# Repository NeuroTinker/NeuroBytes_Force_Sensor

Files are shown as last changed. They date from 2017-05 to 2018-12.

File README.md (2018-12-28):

# NeuroBytes Pressure Sensory Neuron
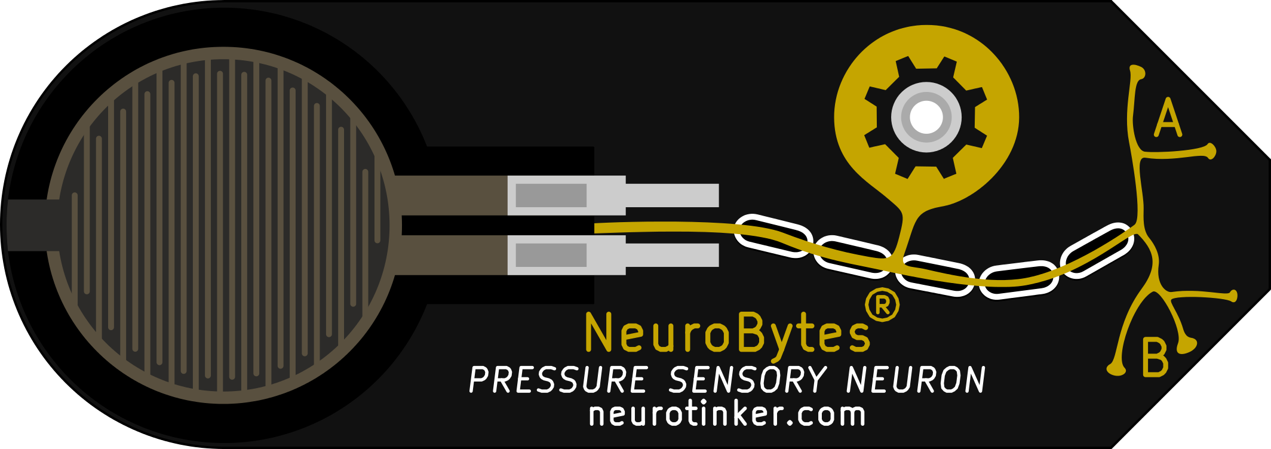
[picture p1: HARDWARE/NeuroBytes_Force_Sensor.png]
NeuroBytes Force Sensory Neuron PCB front

The NeuroBytes Pressure Sensory Neuron is an open-source hardware neuron simulator designed and sold by [NeuroTinker, LLC](http://www.neurotinker.com/). 

All NeuroBytes products are based on the ST32L0x series of ARM Cortex-M0+ 32-bit microcontrollers. The boards were designed in KiCad and Inkscape and are released under the terms of the Creative Commons Attribution-ShareAlike 4.0 license, available here: http://creativecommons.org/licenses/by-sa/4.0/. The NeuroBytes Pressure Sensory Neuron is Certified Open Source Hardware as defined by [OSHWA](https://www.oshwa.org), certification number US000111.


OSHWA Certification

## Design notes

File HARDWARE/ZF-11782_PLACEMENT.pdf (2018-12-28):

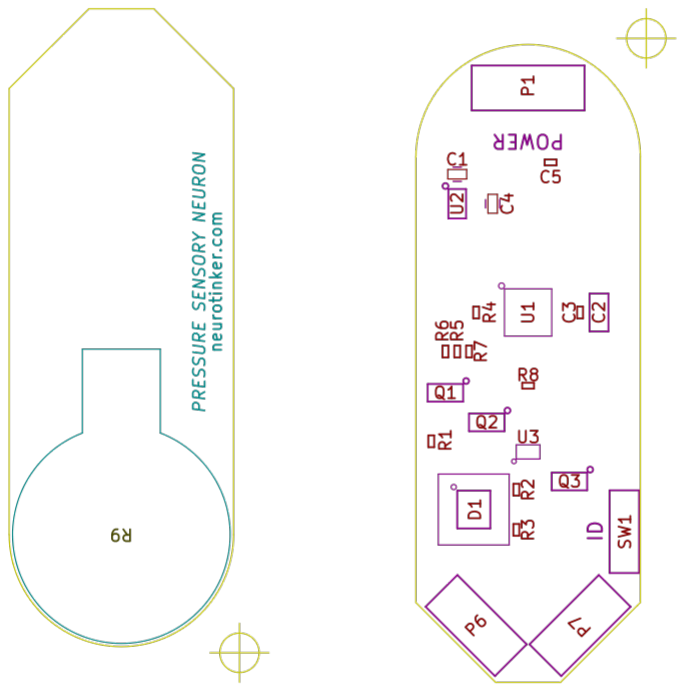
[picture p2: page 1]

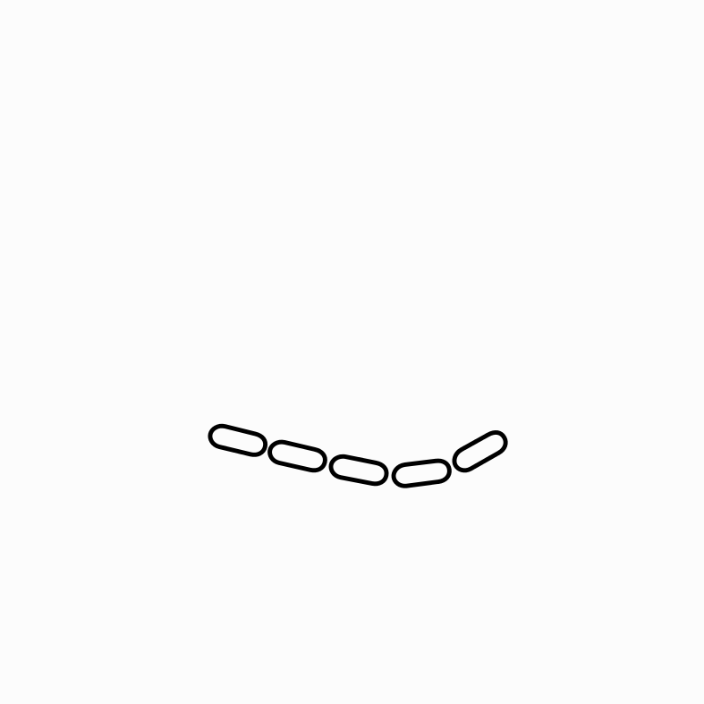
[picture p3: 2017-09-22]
HARDWARE/silk.png

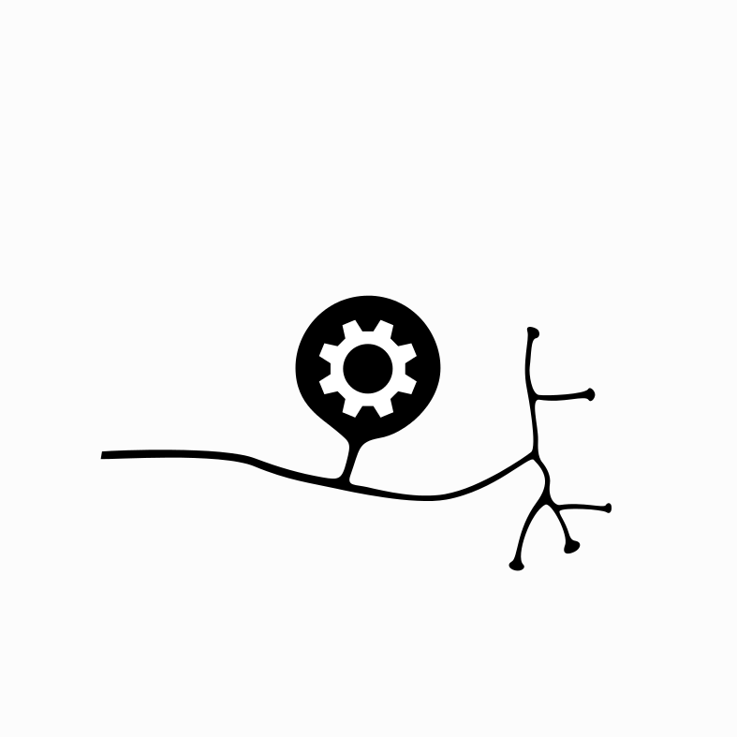
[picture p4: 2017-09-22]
HARDWARE/mask.png

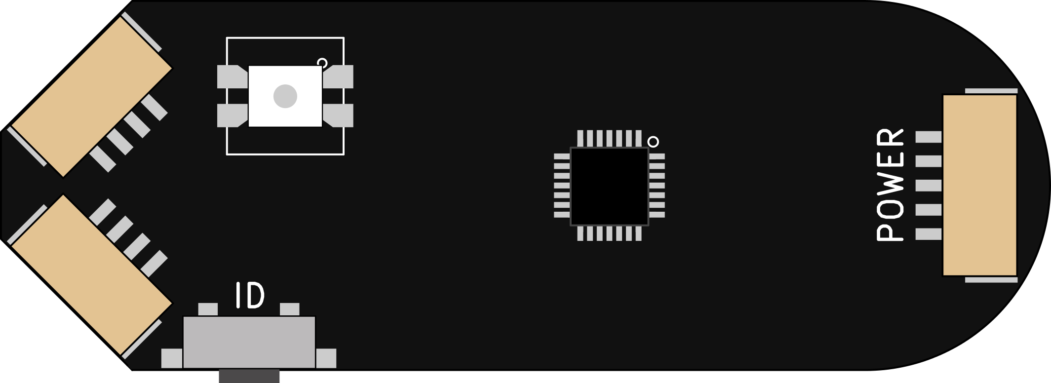
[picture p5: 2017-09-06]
HARDWARE/NeuroBytes_Force_Sensor_back.png

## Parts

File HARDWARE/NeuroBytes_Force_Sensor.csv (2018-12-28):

Ref | Qty | Value | Link | Mfr | Mfr Part # | Package | RoHS | Subs Allowed
C4 C1 | 2 | 1u | https://www.digikey.com/product-detail/en/taiyo-yuden/LMK107B7105KA-T/587-1242-2-ND/930594 | Taiyo Yuden | LMK107B7105KA-T | C0603 | Yes | Yes
C5 C3 | 2 | 0u1 | https://www.digikey.com/product-detail/en/taiyo-yuden/LMK105BJ104KV-F/587-1227-2-ND/930579 | Taiyo Yuden | LMK105BJ104KV-F | C0402 | Yes | Yes
C2 | 1 | 10u | https://www.digikey.com/product-detail/en/taiyo-yuden/EMK316B7106KL-TD/587-2395-2-ND/2178914 | Taiyo Yuden | EMK316B7106KL-TD | C1206 | Yes | Yes
D1 | 1 | LED_RABG | https://www.digikey.com/product-detail/en/sunled/XZMDKCBDDG45S-9/1497-1257-2-ND/4902045 | SunLED | XZMDKCBDDG45S-9 | SMT | Yes | No
P6 P7 | 2 | CONN_01X04 | https://www.digikey.com/product-detail/en/jst-sales-america-inc/SM04B-GHS-TB-LF-SN/455-1566-2-ND/807788 | JST | SM04B-GHS-TB(LF)(SN) | SMT | Yes | No
P1 | 1 | JST_GH_5-pos | https://www.digikey.com/product-detail/en/jst-sales-america-inc/SM05B-GHS-TB-LF-SN/455-1567-2-ND/807789 | JST | SM05B-GHS-TB(LF)(SN) | SMT | Yes | No
Q1 Q2 Q3 | 3 | MMBT3904 | https://www.digikey.com/product-detail/en/micro-commercial-co/MMBT3904-TP/MMBT3904TPMSTR-ND/717280 | Micro Commercial Co | MMBT3904-TP | SOT23-3 | Yes | Yes
R1 | 1 | 150 | https://www.digikey.com/product-detail/en/yageo/RC0402FR-07150RL/311-150LRCT-ND/729490 | Yageo | RC0402FR-07150RL | R0402 | Yes | Yes
R2 R3 | 2 | 100 | https://www.digikey.com/product-detail/en/yageo/RC0402FR-07100RL/311-100LRTR-ND/726527 | Yageo | RC0402FR-07100RL | R0402 | Yes | Yes
R4 | 1 | JMP | https://www.digikey.com/product-detail/en/yageo/RC0402JR-070RL/311-0.0JRTR-ND/726406 | Yageo | RC0402JR-070RL | R0402 | Yes | Yes
R8 | 1 | 10k | https://www.digikey.com/product-detail/en/yageo/RC0402FR-0710KL/311-10.0KLRTR-ND/726523 | Yageo | RC0402FR-0710KL | R0402 | Yes | Yes
R9 | 1 | R_Variable | https://www.digikey.com/product-detail/en/interlink-electronics/34-00015/1027-1018-ND/5416350 | Interlink Electronics | 34-00015 | SMT | Yes | No
R5 R6 R7 | 3 | 1k | https://www.digikey.com/product-detail/en/yageo/RC0402FR-071KL/311-1.00KLRTR-ND/726513 | Yageo | RC0402FR-071KL | R0402 | Yes | Yes
SW1 | 1 | SW_PUSH | https://www.digikey.com/product-detail/en/e-switch/TL3330AF130QG/EG4388TR-ND/1426835 | E-Switch | TL3330AF130QG | SMT | Yes | No
U1 | 1 | STM32L011Gx | http://www.mouser.com/ProductDetail/STMicroelectronics/STM32L011G4U6/ | ST Microelectronics | STM32L011G4U6 | 28-UFQFN | Yes | No
U3 | 1 | RClamp0503F | https://www.digikey.com/product-detail/en/semtech-corporation/RCLAMP0503F.TCT/RCLAMP0503F.TCTTR-ND/5113629 | Semtec Corporation | RCLAMP0503F.TCT | 5-TSSOP | Yes | No
BOM made with KICAD_BOM_WIZARD (https://github.com/HashDefineElectronics/KiCad_BOM_Wizard.git)
Generated Wed 23 May 2018 02:29:42 PM CDT

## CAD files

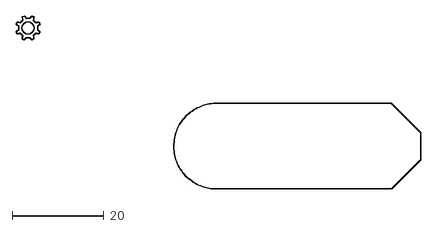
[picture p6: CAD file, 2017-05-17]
HARDWARE/NeuroBytes_Force_Sensor.dxf
88.5 x 37.8

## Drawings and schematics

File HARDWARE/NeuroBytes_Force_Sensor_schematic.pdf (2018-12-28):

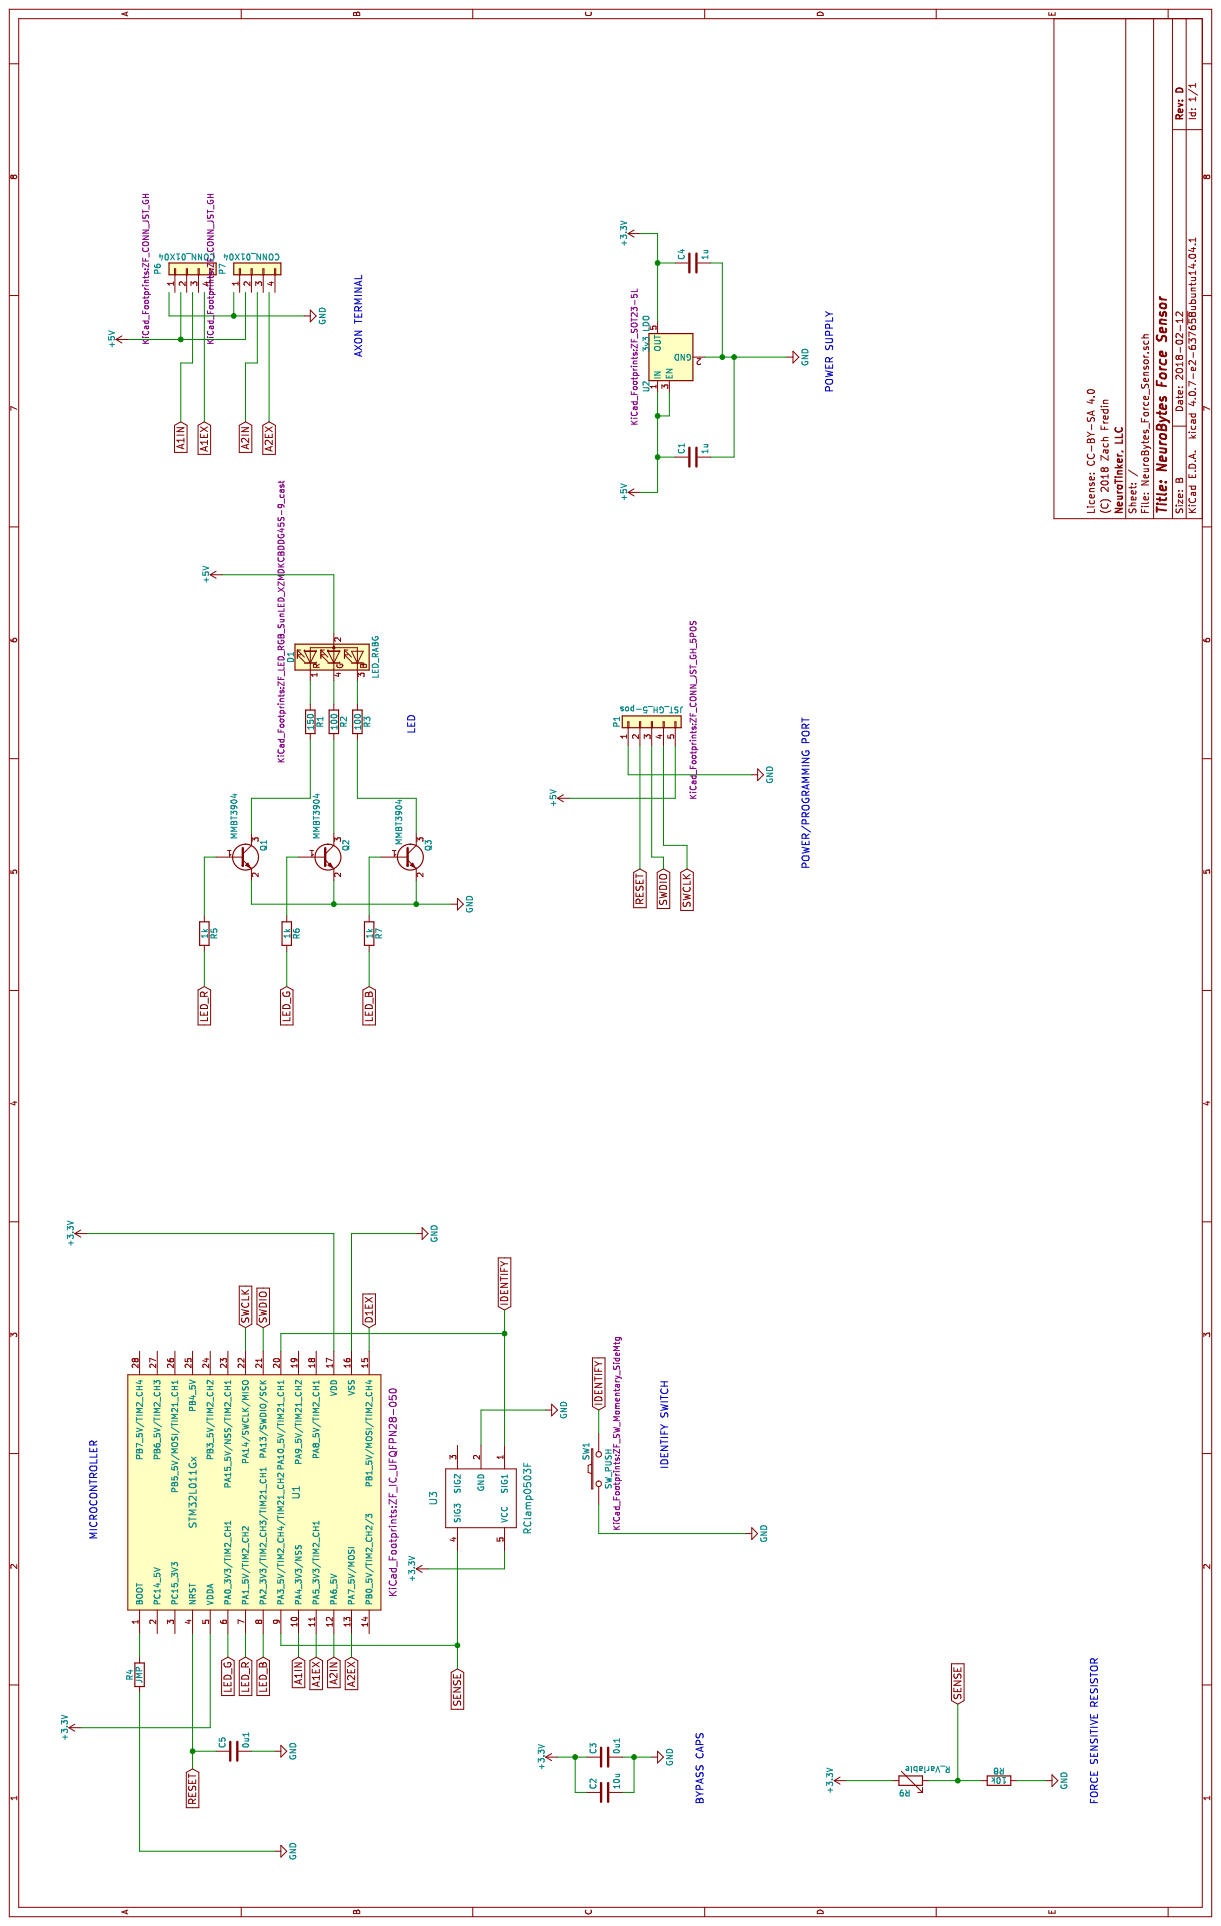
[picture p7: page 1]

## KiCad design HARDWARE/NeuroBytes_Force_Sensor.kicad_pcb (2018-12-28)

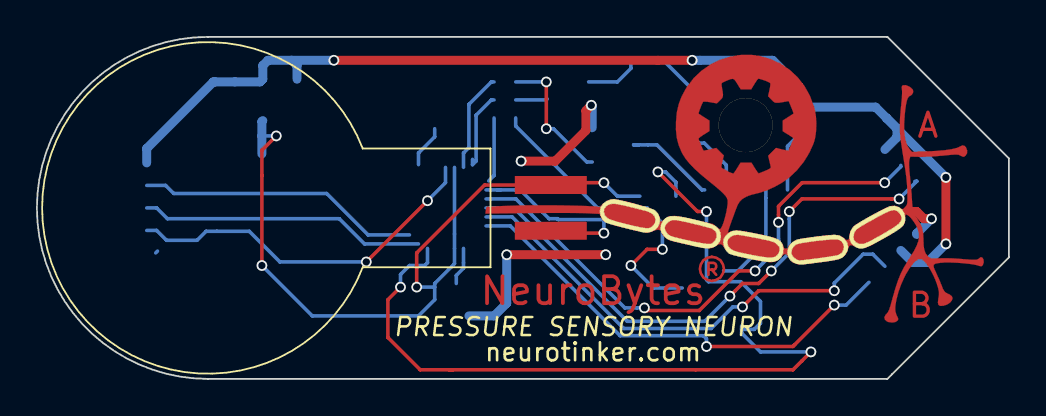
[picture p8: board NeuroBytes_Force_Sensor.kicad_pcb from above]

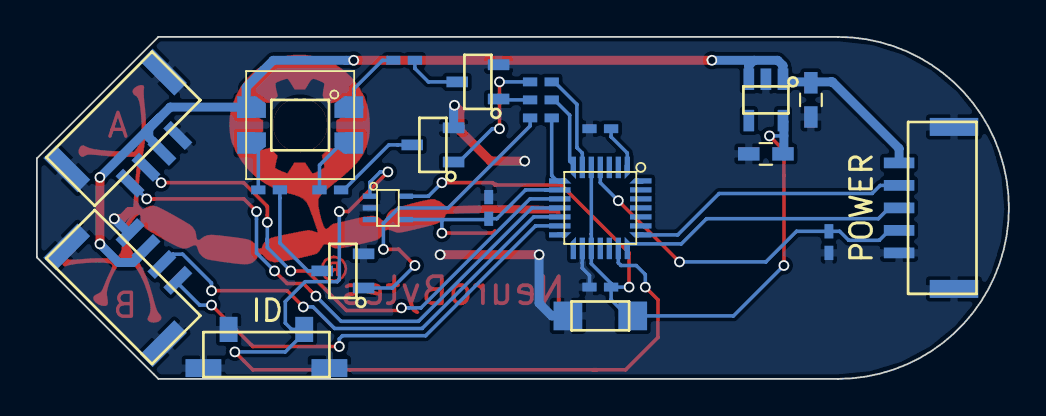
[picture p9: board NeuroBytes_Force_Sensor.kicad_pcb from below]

Board: 2 copper layers, 54.0 x 19.0 mm, 25 parts (24 on the bottom side), 25 nets.

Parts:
C1, C4: 1u; C_0603_HandSoldering
C2: 10u; ZF_SMD_nonpol_1206
C3, C5: 0u1; ZF_SMD_NonPol_0402_cap
D1: LED_RABG; ZF_LED_RGB_SunLED_XZMDKCBDDG45S-9_cast
P1: JST_GH_5-pos; ZF_CONN_JST_GH_5POS
P6, P7: CONN_01X04; ZF_CONN_JST_GH
Q1, Q2, Q3: MMBT3904; ZF_SOT23-3L
R1: 150; ZF_SMD_NonPol_0402
R2, R3: 100; ZF_SMD_NonPol_0402
R4: JMP; ZF_SMD_NonPol_0402
R5, R6, R7: 1k; ZF_SMD_NonPol_0402
R8: 10k; ZF_SMD_NonPol_0402
R9: R_Variable; ZF_SENSOR_FSR_34-00015
SW1: SW_PUSH; ZF_SW_Momentary_SideMtg
U1: STM32L011Gx; ZF_IC_UFQFPN28-050
U2: 3v3 LDO; ZF_SOT23-5L
U3: RClamp0503F; ZF_SMD_SOT-353

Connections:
+3V3: C2.1, C3.1, C4.1, R9.2, U1.5, U1.17, U2.5, U3.5
+5V: C1.1, D1.2, P1.5, P6.2, P7.2, U2.1, U2.3
A1EX: P6.4, U1.11
A1IN: P6.3, U1.10
A2EX: P7.4, U1.13
A2IN: P7.3, U1.12
GND: C1.2, C2.2, C3.2, C4.2, C5.2, P1.1, P6.1, P7.1, Q1.2, Q2.2, Q3.2, R4.1, R8.2, SW1.1, U1.16, U2.2, U3.2
IDENTIFY: SW1.2, U1.20, U3.1
LED_B: R7.2, U1.8
LED_G: R6.2, U1.6
LED_R: R5.2, U1.7
unnamed: D1.1, R1.1
unnamed: D1.3, R3.1
unnamed: D1.4, R2.1
unnamed: Q1.1, R5.1
unnamed: Q1.3, R1.2
unnamed: Q2.1, R6.1
unnamed: Q2.3, R2.2
unnamed: Q3.1, R7.1
unnamed: Q3.3, R3.2
unnamed: R4.2, U1.1
RESET: C5.1, P1.2, U1.4
SENSE: R8.1, R9.1, U1.9, U3.4
SWCLK: P1.4, U1.22
SWDIO: P1.3, U1.21

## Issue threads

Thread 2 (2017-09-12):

change to pressure sensory neuron (from force sensory neuron)

zakqwy, 2017-09-12:

jrwhite, 2017-09-22:
It looks like the latest merge fixed this issue.

Closed 2017-09-26.

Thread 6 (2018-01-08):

Desensitization

NeuroTinkerJoe, 2018-01-08:
The Pressure Sensory Neuron should desensitize similarly to how the Touch Sensory Neuron currently does.

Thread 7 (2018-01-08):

Labeling

NeuroTinkerJoe, 2018-01-08:
To stay consistent with physiological terminology, the final board should be labeled "Pressure Sensory Neuron" instead of "Force Sensory Neuron".

zakqwy, 2018-01-08:
Already done on the newest PCB designs. Not yet reflected in illustrations.

Closed 2018-01-08.

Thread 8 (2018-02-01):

Graded/Action Potentials

NeuroTinkerJoe, 2018-02-01:
Using the app, membrane potential visualization increases as the pressure sensor gets pressed harder and the LED moves towards red. When an action potential is fired however, there is no spike in membrane potential, it stays about the same level as a depolarization just below threshold (red LED), and then hyperpolarizes quickly.

jrwhite, 2018-02-01:
How far above threshold should the membrane potential spike as it fires an AP?

NeuroTinkerJoe, 2018-02-01:
I'll send more info and a graph along tomorrow for an idealized waveform

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

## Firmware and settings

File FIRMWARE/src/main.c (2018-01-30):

#include <libopencm3/stm32/rcc.h>
#include <libopencm3/stm32/gpio.h>
#include <libopencm3/stm32/timer.h>
#include <libopencm3/stm32/adc.h>
#include <libopencm3/cm3/nvic.h>
#include <libopencm3/cm3/systick.h>
#include <libopencm3/stm32/exti.h>
#include <libopencm3/stm32/usart.h>

#include "HAL.h"
#include "comm.h"
#include "neuron.h"

// #define DBG

#define BLINK_TIME			40
#define DATA_TIME			10
#define DEND_PING_TIME		200 // 1000 ms
#define	NID_PING_TIME		200 // 1000 ms
#define SEND_PING_TIME		80
#define BUTTON_PRESS_TIME	2
#define BUTTON_HOLD_TIME    100
#define LPUART_SETUP_TIME	100
#define CHANGE_NID_TIME 	200
#define ADAPT_TIME			6

static uint32_t fingerprint[3] __attribute__((section (".fingerprint"))) __attribute__ ((__used__)) = {
	7, // device id
	1, // firmware version
	0  // unique id
};


int	adaptation_rate = 0; 
int	adaptive_zero = 0;
int	sense_input;
int	sense_10_bit;
int	current_sense;
int	zero = 0; // 165 circle
int	span = 10000; // 3000 circle
int	fire_time = 0;
int	fire_led = 0;
int	zero_freq = 150;
int adapt_time = 0;

typedef enum{
	CURRENT		=	0b0001,
	ADAPT 		=	0b0010
} parameter_identifiers;

int scale10bit(int val, int zero, int span) 
{
	/*	Scales input based on zero and span calibration points. Returns unsigned
		10-bit integer as output (i.e. 0-1023). */

	if (zero < span) 
	{
		if ((val > zero) && (val < span))
		{
			return ((val - zero) * 1023) / (span - zero);
		}
		else if (val <= zero)
		{
			return 0;
		}
		else 
		{
			return 1023;
		}
	}
	else 
	{
		return val;
	}
}

int main(void)
{
	uint32_t	blink_time = 0;
	uint32_t	wait_time = 0;
	uint16_t	data_time = 0;
	uint16_t	message_data = 0;
	uint16_t	send_ping_time = 0;
	uint16_t	button_press_time = 0;
	uint8_t		button_armed = 0;
	uint16_t	button_status = 0;
	uint32_t	nid_channel = 0b000; //debug
	uint8_t		fire_flag = 0;
	uint8_t		fire_tick = 0;
	uint16_t	lpuart_setup_time = 0;
	uint8_t		change_nid_time = 0;

	int16_t fire_data = 0;
	uint16_t fire_delay_time = 0;
	uint16_t fire_delay_time_reset = FIRE_DELAY_TIME;
	fire_delay_time_reset = 40; // temporary
	uint16_t fire_delay_overflow = 0;

	message_t message;

	neuron_t 	neuron;
	uint8_t		i;
	neuronInit(&neuron);
	commInit();

	clock_setup();
	systick_setup(100);
	gpio_setup();
	tim_setup();
	gpio_setup();
	adc_setup();

	#ifdef DBG
	blink_flag = 1;
	#endif
	
	for(;;)
	{
		
		// adc_start_conversion_regular(ADC1);
		// while (!(adc_eoc(ADC1)));
		// sense_input = adc_read_regular(ADC1);
		// sense_10_bit = scale10bit(sense_input, zero, span);
		
		if (main_tick == 1){
			// 5 ms
			main_tick = 0;

			adc_start_conversion_regular(ADC1);
			while (!(adc_eoc(ADC1)));
			sense_input = adc_read_regular(ADC1);
			sense_10_bit = scale10bit(sense_input, zero, span);
			current_sense = sense_10_bit - adaptive_zero;

			//adapt_time = 0; // debug
			if (++adapt_time == ADAPT_TIME){
				adapt_time = 0;
				if (adaptation_rate != 0){
					if (current_sense > 0){
						adaptive_zero += current_sense * adaptation_rate / 100;
					} else if (current_sense < 0){
						adaptive_zero -= -1 * current_sense * adaptation_rate / 100;
					}
				}
			}
			
			// check to see if nid ping hasn't been received in last NID_PING_TIME ticks
			if (nid_ping_time > 0){
				nid_ping_time -= 1;
				if (nid_ping_time == 0){
					// nid no longer connected
					nid_distance = 100; // reset nid_keep_alive
					nid_pin = 0; // clear the nid pin
					nid_pin_out = 0;
					nid_i = NO_NID_I;
				}
			}

			if (lpuart_setup_time < LPUART_SETUP_TIME){
				lpuart_setup_time += 1;
			} else if (lpuart_setup_time == LPUART_SETUP_TIME){
				lpuart_setup_time += 1;
				#ifndef DBG
				lpuart_setup();
				#endif
			}
			
			if (change_nid_time++ > CHANGE_NID_TIME){
				change_nid_time = 0;
				closer_distance = nid_distance;
				closer_ping_count = 0;
			}
			
			// send a downstream ping every SEND_PING_TIME ticks
			if (send_ping_time++ > SEND_PING_TIME){
				// send downstream ping through axon
				addWrite(DOWNSTREAM_BUFF, downstream_ping_message);
				send_ping_time = 0;
			}


			if (comms_flag != 0){
				switch (comms_flag){
					case ADAPT:
						adaptation_rate = comms_data;	
						break;
					default:
						break;
				}
				comms_flag = 0;
				comms_data = 0;
			}

			// check for clear channel command
			if (identify_time < IDENTIFY_TIME){
				if (identify_time == 0){
					if ((identify_channel == 0) || (identify_channel == nid_channel)){
						nid_channel = 0;
					}
				}
				identify_time += 1;
			}
			
			// check identify button
			button_status = gpio_get(PORT_IDENTIFY, PIN_IDENTIFY);

			// if identify button is pressed and identify_time < IDENTIFY_TIME (i.e. NID sent 'identify'' message), set new nid_channel
			if (button_status == 0){
				// debounce
				button_press_time += 1;
				if (button_press_time >= BUTTON_HOLD_TIME){
					button_armed = 2;
					blink_flag = 1;
				} else if (button_press_time >= BUTTON_PRESS_TIME){
					button_armed = 1;
				}
			} else{
				// button not pressed
				if (button_armed == 0){
					button_press_time = 0;
				} else if (button_armed == 1 && nid_i != NO_NID_I){
					nid_channel = identify_channel;
					identify_time = 1;
					button_armed = 0;
				} else if (button_armed == 2){
					if (adaptation_rate > 0){
						adaptation_rate = 0;
						adaptive_zero = 0;
					} else{
						//adaptation_rate = 1;
						adaptation_rate = 0;
					}
					button_armed = 0;
				}
				button_press_time = 0;
			}
			
			// send current membrane potential to NID if currently identified by NID
			if (nid_channel != 0){
				// send data every DATA_TIME ticks
				if (data_time++ > DATA_TIME){
					if (fire_data > 0){
						if (fire_data == 1){
							message.message = (((uint32_t) DATA_MESSAGE)) | ((uint16_t) HYPERPOLARIZATION);
							fire_data = 0;						
						} else {
							message.message = (((uint32_t) DATA_MESSAGE)) | ((uint16_t) fire_data);	
							fire_data = 1;						
						}
					} else {
						message.message = (((uint32_t) DATA_MESSAGE)) | ((uint16_t) neuron.potential);						
					}
					data_time = 0;
					message.length = 32;
					message.message |= (nid_channel << 21);
					addWrite(NID_BUFF,(const message_t) message);
				}
			}

			neuron.leaky_current = current_sense * 9 / 10;
			membraneDecayStep(&neuron);
			neuron.potential = 0;
			neuron.potential += neuron.fire_potential;
			neuron.fire_potential += neuron.leaky_current;

			// if membrane potential is greater than threshold, fire
			if (neuron.potential > MEMBRANE_THRESHOLD){
				// fire for determined pulse width
				neuron.state = FIRE;
				neuron.fire_potential = HYPERPOLARIZATION;
				neuron.fire_time = PULSE_LENGTH;

				fire_data = neuron.potential;

				if (fire_delay_time == 0) {
					fire_delay_time = fire_delay_time_reset;
					fire_delay_overflow = 0;
				} else {
					fire_delay_overflow = fire_delay_time_reset - fire_delay_time;
				}

				fire_flag = 1;
			} else if (neuron.potential < HYPERPOLARIZATION) {
				neuron.potential = HYPERPOLARIZATION;
			}

			if (fire_delay_time > 0){
				fire_delay_time -= 1;
			} else if (fire_flag == 1){
				if (fire_delay_overflow > 0)
					fire_delay_time = fire_delay_overflow; // TODO: make this an actual FIFO buffer of fire timings
				fire_flag = 0;
				addWrite(DOWNSTREAM_BUFF, pulse_message);
			}
			
			if (blink_flag != 0){
				setLED(200,0,300);
				blink_time = 1;
				blink_flag = 0;
			} else if (blink_time > 0){
				if (++blink_time == BLINK_TIME){
					setLED(200,0,200);
					blink_time = 0;
				}
			}else if (neuron.state == FIRE){
				neuron.fire_time -= 1;
				if (neuron.fire_time == 0){
					neuron.state = INTEGRATE;
				}
				LEDFullWhite();
			} else if (neuron.state == INTEGRATE){
				if (neuron.potential > 10000){
					setLED(200,0,0);
				} else if (neuron.potential > 0){
					setLED(neuron.potential / 50, 200 - (neuron.potential / 50), 0);
				} else if (neuron.potential < -10000){
					setLED(0,0, 200);
				} else if (neuron.potential < 0){
					setLED(0, 200 + (neuron.potential / 50), -1 * neuron.potential / 50);
				} else{
					setLED(0,200,0);
				}
			}
		}
	}
}

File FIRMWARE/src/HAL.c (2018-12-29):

#include <libopencm3/stm32/rcc.h>
#include <libopencm3/stm32/gpio.h>
#include <libopencm3/stm32/timer.h>
#include <libopencm3/stm32/adc.h>
#include <libopencm3/cm3/nvic.h>
#include <libopencm3/cm3/systick.h>
#include <libopencm3/stm32/usart.h>

#include "HAL.h"
#include "comm.h"

volatile uint8_t toggle = 0;
volatile uint8_t tick = 0;
extern volatile uint8_t main_tick = 0;
volatile uint8_t read_tick = 0;

volatile uint16_t active_input_pins[NUM_INPUTS] = {[0 ... NUM_INPUTS-1] = 0};

volatile uint8_t active_input_tick[NUM_INPUTS] = {[0 ... NUM_INPUTS-1] = 0};

volatile uint16_t active_output_pins[NUM_INPUTS] = {PIN_AXON1_EX, PIN_AXON2_EX};

volatile uint32_t dendrite_pulses[];
volatile uint8_t dendrite_pulse_count = 0;

uint8_t channel_array[] =  {0, 0, 1}; // TODO: why is this here?

uint32_t active_input_ports[NUM_INPUTS] = {
	PORT_AXON1_EX,
	PORT_AXON2_EX
};

uint32_t active_output_ports[NUM_INPUTS] = {
	PORT_AXON1_IN,
	PORT_AXON2_IN
};

const uint16_t complimentary_pins[NUM_INPUTS] = {
	PIN_AXON1_EX,
	PIN_AXON2_EX
};

const uint32_t complimentary_ports[NUM_INPUTS] = {
	PORT_AXON1_EX,
	PORT_AXON2_EX
};

volatile uint8_t dendrite_pulse_flag[];
volatile uint8_t dendrite_ping_flag[];

static uint32_t fingerprint[3] __attribute__((section (".fingerprint"))) __attribute__ ((__used__)) = {
	6, // device id
	1, // firmware version
	0  // unique id
};

bool checkVersion(device_id, version) {return (device_id == fingerprint[0]) && (version = fingerprint[1]) ? true : false;}

void clock_setup(void)
{
	// STM32F0 command:	rcc_clock_setup_in_hsi_out_48mhz();
	rcc_set_sysclk_source(RCC_HSI16);
	rcc_osc_on(RCC_HSI16);
}

void sys_tick_handler(void)
{
	// gpio_toggle(PORT_AXON_OUT, PIN_AXON_OUT);
	if (++tick >= 50){
		main_tick = 1;
		tick = 0;
	}

	if (read_tick++ >= 2){
		writeBit();
		read_tick = 0;
	}

	readBit(read_tick);
}

void systick_setup(int xms)
{
	
    systick_set_clocksource(STK_CSR_CLKSOURCE_EXT);
    STK_CVR = 0;
    systick_set_reload(180);
    systick_counter_enable();
    systick_interrupt_enable();
	
}

void adc_setup(void)
{
	/*	Light sensor is on PA1 (ADC1) */
	
	int i;

	/*	Enable ADC clock */
	rcc_periph_clock_enable(RCC_ADC1);

	/*	Make sure ADC is off during config! */
	adc_power_off(ADC1);

	/*	ADC config */
		
	adc_set_single_conversion_mode(ADC1);
	adc_set_right_aligned(ADC1);
	adc_calibrate(ADC1);
	adc_set_resolution(ADC1, ADC_CFGR1_RES_12_BIT);


	/*	adc_set_regular_sequence(adc, length, channel[]) isn't working, so this snippit
		_should_ set up channel 1. */	
	MMIO32((ADC1) + 0x28) |= 1 << 3;
	//MMIO32((ADC1) + 0x28) |= 1 << 1;

	/*	Turn on ADC and wait a bit */
	adc_power_on(ADC1);
	for (i=0;i<800000;i++)
	{
		__asm__("nop");
	}
}

void gpio_setup(void)
{
	/*	Enable GPIO clocks */
	rcc_periph_clock_enable(RCC_GPIOA);
	rcc_periph_clock_enable(RCC_GPIOB);
	rcc_periph_clock_enable(RCC_GPIOC);

	rcc_periph_clock_enable(RCC_ADC1); // enable ADC 1

	rcc_peripheral_enable_clock(&RCC_APB2ENR, RCC_APB2ENR_SYSCFGEN); // this line took a long time

	/*	Set up LED pins:
		Alternative Function Mode with no pullup/pulldown
		Output options: push-pull, high speed
		PIN_R_LED (PA1): AF2, TIM2_CH2
		PIN_G_LED (PA0): AF2, TIM2_CH1
		PIN_B_LED (PA2): AF2, TIM2_CH3 */
	gpio_mode_setup(PORT_R_LED, GPIO_MODE_AF, GPIO_PUPD_NONE, PIN_R_LED);
	gpio_mode_setup(PORT_G_LED, GPIO_MODE_AF, GPIO_PUPD_NONE, PIN_G_LED);
	gpio_mode_setup(PORT_B_LED, GPIO_MODE_AF, GPIO_PUPD_NONE, PIN_B_LED);
	gpio_set_output_options(PORT_R_LED, GPIO_OTYPE_PP, GPIO_OSPEED_LOW, PIN_R_LED);
	gpio_set_output_options(PORT_G_LED, GPIO_OTYPE_PP, GPIO_OSPEED_LOW, PIN_G_LED);
	gpio_set_output_options(PORT_B_LED, GPIO_OTYPE_PP, GPIO_OSPEED_LOW, PIN_B_LED);
	gpio_set_af(PORT_R_LED, GPIO_AF2, PIN_R_LED);
	gpio_set_af(PORT_G_LED, GPIO_AF2, PIN_G_LED);
	gpio_set_af(PORT_B_LED, GPIO_AF2, PIN_B_LED);

	/*	Set up ADC input */
	gpio_mode_setup(PORT_SENSE, GPIO_MODE_ANALOG, GPIO_PUPD_NONE, PIN_SENSE);

	/*	Set up button inputs */
	gpio_mode_setup(PORT_IDENTIFY, GPIO_MODE_INPUT, GPIO_PUPD_PULLUP, PIN_IDENTIFY);

	setAsInput(PORT_AXON1_IN, PIN_AXON1_IN);
	setAsInput(PORT_AXON2_IN, PIN_AXON2_IN);
	setAsOutput(PORT_AXON1_EX, PIN_AXON1_EX);
	setAsOutput(PORT_AXON2_EX, PIN_AXON2_EX);
	
	nvic_enable_irq(NVIC_EXTI0_1_IRQ);
	nvic_enable_irq(NVIC_EXTI2_3_IRQ);
	nvic_enable_irq(NVIC_EXTI4_15_IRQ);

	nvic_set_priority(NVIC_EXTI0_1_IRQ, 0);
	nvic_set_priority(NVIC_EXTI2_3_IRQ, 0);
	nvic_set_priority(NVIC_EXTI4_15_IRQ, 0);
	//MMIO32(SYSCFG_BASE + 0x0c) = 0b0101 << 12;

	//MMIO32((EXTI_BASE) + 0x14) |= (1<<1);
}


void lpuart_setup(void)
{
	// seutp lpuart interface (for communicating with NID)
	// NOTE: this ocnverts the swd interface to lpuart so debugging with swd will be disables
	rcc_periph_clock_enable(RCC_LPUART1);

	gpio_mode_setup(PORT_LPUART1_RX, GPIO_MODE_AF, GPIO_PUPD_NONE, PIN_LPUART1_RX);
	gpio_mode_setup(PORT_LPUART1_TX, GPIO_MODE_AF, GPIO_PUPD_NONE, PIN_LPUART1_TX);

	gpio_set_af(PORT_LPUART1_RX, GPIO_AF6, PIN_LPUART1_RX);
	gpio_set_af(PORT_LPUART1_TX, GPIO_AF6, PIN_LPUART1_TX);

	USART_BRR(LPUART1) = 0x1A0AA; // 38400 baud
	usart_set_databits(LPUART1, 8);  // USART_CR1_M
	usart_set_stopbits(LPUART1, USART_STOPBITS_1); //USART_CR2_STOP
	usart_set_mode(LPUART1, USART_MODE_TX_RX); //USART_CR1_RE USART_CR1_TE
	usart_set_parity(LPUART1, USART_PARITY_NONE);// USART_CR1_PS USART_CR1_PCE
	usart_set_flow_control(LPUART1, USART_FLOWCONTROL_NONE); // USART_CR3_RTSE USART_CR3_CTSE

	usart_enable(LPUART1); // USART_CR1_UE

	// enable interrupts
	nvic_enable_irq(NVIC_LPUART1_IRQ);
	usart_enable_rx_interrupt(LPUART1); // USART_CR1_RXNEIE
    USART_CR1(LPUART1) |= USART_CR1_RE;
    USART_CR1(LPUART1) |= USART_CR1_TE;
}

void lpuart1_isr(void)
{
    if ((USART_ISR(LPUART1) & USART_ISR_RXNE) != 0){
        readNID();
        USART_RQR(LPUART1) = 0b1000;
        USART_CR1(LPUART1) |= USART_CR1_RE;
    } else if ((USART_ISR(LPUART1) & USART_ISR_TXE) != 0){
        /* USART_CR1(LPUART1) |= USART_CR1_TE; */
        writeNID();
        USART_RQR(LPUART1) |= USART_RQR_TXFRQ;
    }
    USART_ICR(LPUART1) = USART_ISR(LPUART1);
}

void setAsInput(uint32_t port, uint32_t pin)
{
	// setup gpio as an input pin
	gpio_mode_setup(port, GPIO_MODE_INPUT, GPIO_PUPD_PULLDOWN, pin);

	// setup interrupt for the pin going high
	exti_select_source(pin, port);
	exti_set_trigger(pin, EXTI_TRIGGER_RISING);
	exti_enable_request(pin);
	exti_reset_request(pin);
}

void setAsOutput(uint32_t port, uint32_t pin)
{
	// disable input interrupts
	exti_disable_request(pin);

	// setup gpio as an output pin. pulldown
	gpio_mode_setup(port, GPIO_MODE_OUTPUT, GPIO_PUPD_PULLDOWN, pin);
}

// working interrupt pins: 0,1,3,4,6,7

/*
	Each input's ISR tells the communications program that the input is active (getting a message).
	For dendrite inputs, the ISR also tells the neuron program if the input is excitatory or inhibitory and then toggles input/output
*/
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

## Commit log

2017-04-24 Initial commit -- first rev hardware and test firmware.
    [NeuroBytes_Force_Sensor.kicad_pcb, NeuroBytes_Force_Sensor.sch]
2017-05-15 added schematic library submodule
2017-05-17 Second PCB spin. Added unipolar neuron graphics and changed indication mode to 'traditional' NeuroTinker bottom-mount RGB LED. Added letters for dendrites. Updated title block to standard format. Man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
    [NeuroBytes_Force_Sensor.dxf]
2017-05-25 Got rid of compiled files. Updated schematic LED global labels to correct values. Updated HAL.c and HAL.h to new hardware design (neuron graphics, RGB LED, etc). Changed main.c to simple test program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
    [NeuroBytes_Force_Sensor.sch]
2017-06-29 Updated PCB design files. Generated paste Gerber for stencil.
    [NeuroBytes_Force_Sensor.kicad_pcb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]
2017-08-11 added fingerprint
2017-08-11 updated power connector to 5-pin JST GH. minor routing/labeling changes.
    [NeuroBytes_Force_Sensor.kicad_pcb, NeuroBytes_Force_Sensor.sch]
2017-08-11 changed fingerprint
2017-08-28 added kicad text to *.svg file. added *.png render of board front.
2017-09-06 added board back img
2017-09-20 removed old design files from dev branch
    [NeuroBytes_Force_Sensor.kicad_pcb, NeuroBytes_Force_Sensor.sch]
2017-09-20 update dev branch with hardware files from master
    [NeuroBytes_Force_Sensor.kicad_pcb, NeuroBytes_Force_Sensor.sch]
2017-09-20 changed to Pressure Sensory Neuron
    [NeuroBytes_Force_Sensor.kicad_pcb]
2017-09-22 cleaned up /FIRMWARE and resolved merge conflicts
    [NeuroBytes_Force_Sensor.kicad_pcb]
2017-09-22 updated to new gear on *.svg and PCB. pulled back mask on labels. other minor updates.
    [NeuroBytes_Force_Sensor.kicad_pcb]
2017-09-22 removed dual transistors and resistor network. started updating component details.
    [NeuroBytes_Force_Sensor.sch]
2017-09-23 added single NPN transitors and non-networked resistors for LED. fresh fab file exports. added fab notes. other minor updates.
    [NeuroBytes_Force_Sensor.csv, NeuroBytes_Force_Sensor.kicad_pcb, NeuroBytes_Force_Sensor.sch]
2017-10-03 page layout updates
    [NeuroBytes_Force_Sensor.kicad_pcb, NeuroBytes_Force_Sensor.sch]
2017-11-29 reduce LED brightness
2017-11-29 updated license to CC-BY-SA 4.0 and readme. added drawing number to PCB.
    [NeuroBytes_Force_Sensor.kicad_pcb]
2018-02-12 added ESD protection
    [NeuroBytes_Force_Sensor.kicad_pcb, NeuroBytes_Force_Sensor.sch]
2018-03-08 updated PCB render text
    [NeuroBytes_Force_Sensor.sch]
2018-03-08 more minor PCB render updates. really just chasing green squares at this point
2018-05-23 generated fab files. added BOM.
    [NeuroBytes_Force_Sensor-B.Cu.gbr, NeuroBytes_Force_Sensor-B.Mask.gbr, NeuroBytes_Force_Sensor-B.Paste.gbr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]
2018-05-23 updated INSERT attribute. regenerated footprint position file.
    [NeuroBytes_Force_Sensor.kicad_pcb]
2018-05-31 exported schematic *.pdf. updated LDO symbol.
    [NeuroBytes_Force_Sensor.sch]
2018-08-08 updated footprints to include B.Fab outlines. minor routing changes. re-generated Gerbers. added placement pdf.
    [NeuroBytes_Force_Sensor-B.Cu.gbr, NeuroBytes_Force_Sensor-B.Mask.gbr, NeuroBytes_Force_Sensor-B.Paste.gbr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]
2018-08-08 regen drill file
    [NeuroBytes_Force_Sensor.drl]
2018-12-28 changed device id to 6

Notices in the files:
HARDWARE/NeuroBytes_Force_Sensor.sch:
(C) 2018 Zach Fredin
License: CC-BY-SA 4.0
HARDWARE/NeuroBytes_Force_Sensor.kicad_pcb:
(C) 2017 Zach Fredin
